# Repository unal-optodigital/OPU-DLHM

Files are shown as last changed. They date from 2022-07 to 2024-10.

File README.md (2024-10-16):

# Optical Pickup Units for DLHM: OPU-DLHM

This repo contains all the suplementary info and files related to the published paper "Adapting a Blu-ray Optical Pickup Unit as a Digital Lensless Holographic Microscopy Point Source". The circuit schematics and boards and the bill of materials will be found on this repo. As well as the most of our developements the info contained in this repo can be used for teaching and research purposes.

## Folders descriptions: 

- The circuit info folder contains the schematic and board design used to electronic-control of the OPU PHR-803T, the designs where adapted and modified from the schematics [presented by the team of Prof. Hwu](https://doi.org/10.1021/acssensors.8b00340).
- The bill of materials folder contains all the needed materials and some usefull .step CAD designs to incorporate the OPU in an standard 30 mm cage system. 

## Reference
Further information about this work can be found in the following publications. These are also the preferred way of citing this tool if you are implementing it in your own works.

- Heberley Tobón-Maya, Alejandra Gómez-Ramírez, Carlos Buitrago-Duque, and Jorge Garcia-Sucerquia, "Adapting a Blu-ray optical pickup unit as a point source for digital lensless holographic microscopy," Appl. Opt. 62, D39-D47 (2023).  
DOI: [10.1364/AO.474916](https://doi.org/10.1364/AO.474916).
- J. García-Sucerquia, C. Trujillo and J. F. Restrepo, "MICROSCOPIO, HOLOGRÁFICO SIN LENTES (MHDSL) Y MÉTODO PARA VISUALIZAR MUESTRAS," U.S. patent 7620179 (2018).

## Contact
- Jorge Garcia-Sucerquia ([jigarcia@unal.edu.co](mailto:jigarcia@unal.edu.co))
- Heberley Tobon-Maya (htobonm@unal.edu.co)
- Alejandra Gomez-Ramirez (alegomezram@unal.edu.co)
- Carlos A. Buitrago-Duque ([cabuitragod@unal.edu.co](mailto:cabuitragod@unal.edu.co))

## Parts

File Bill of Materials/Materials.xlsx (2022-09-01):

Bill of Materials
Designator | Item | Number | Cost Per Unit - USD | Total Cost - USD | Source of Materials | Material Type
Resistor | 2.2K resistor | 5 | 0.05 | 0.25 | Amazon or Aliexpress | Non-specific
Resistor | 18K resistor | 4 | 0.05 | 0.2 | Amazon or Aliexpress | Non-specific
Interface Cable | FFC to DIP 45 Pins | 1 | 1 | 1 | Amazon or Aliexpress | Non-specific
DIP SWITCH | DIP Switch 2 Pins | 1 | 0.25 | 0.25 | Amazon or Aliexpress | Non-specific
Condensers | 1800pF Condenser | 6 | 0.05 | 0.3 | Amazon or Aliexpress | Ceramic
Condensers | 33nF Condenser | 1 | 0.05 | 0.05 | Amazon or Aliexpress | Ceramic
Condensers | 22uF Condenser | 1 | 0.05 | 0.05 | Amazon or Aliexpress | Ceramic
Condensers | 100 uF Condenser | 1 | 0.05 | 0.05 | Amazon or Aliexpress | Ceramic
Condensers | 0.1 uF Condenser | 1 | 0.05 | 0.05 | Amazon or Aliexpress | Ceramic
OPAM | MCP6002(DIP) | 1 | 2 | 2 | Microchip | SemiConductor
Power driver | TC4425(DIP) | 3 | 1.45 | 4.35 | Microchip | SemiConductor

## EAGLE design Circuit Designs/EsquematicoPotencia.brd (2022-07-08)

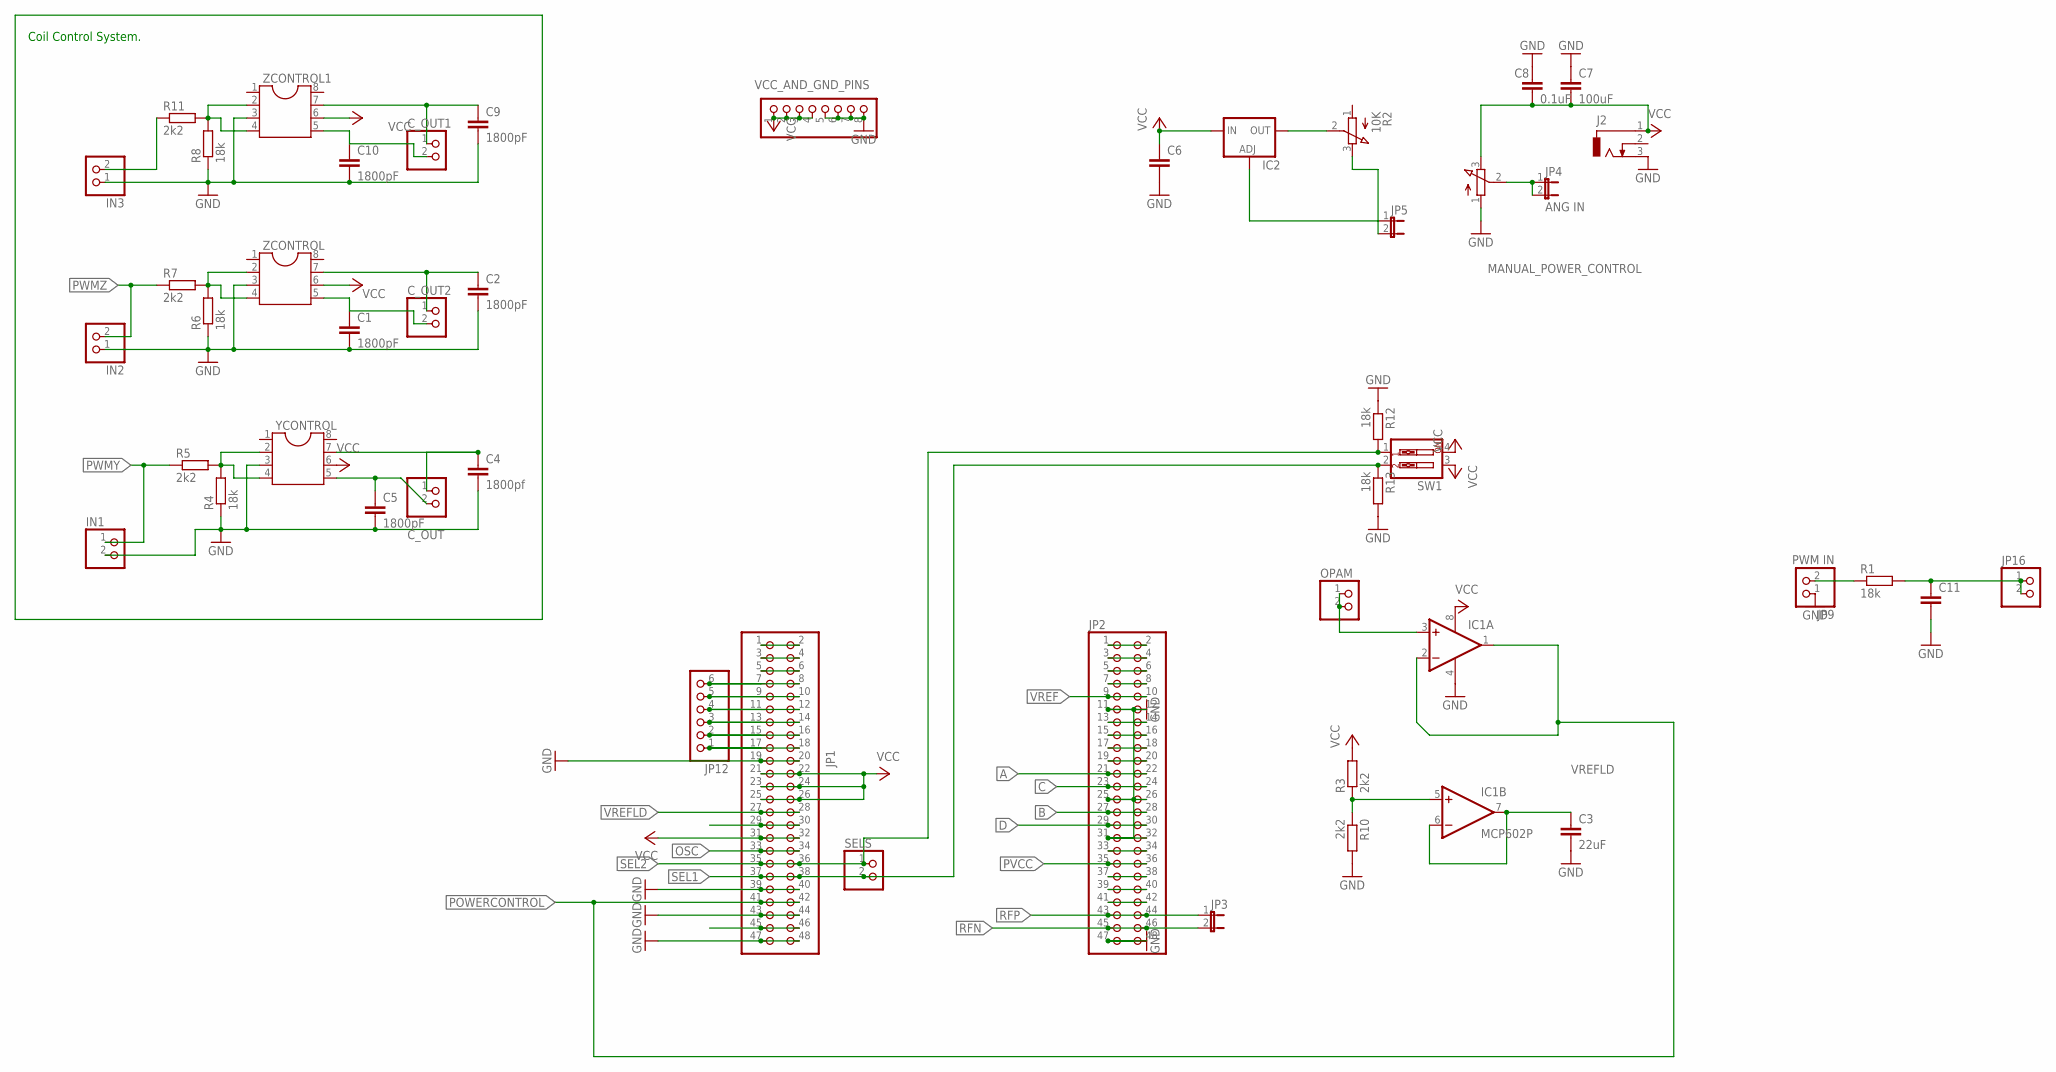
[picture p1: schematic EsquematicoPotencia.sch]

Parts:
C1, C2, C5, C9, C10: 1800pF; C025-024X044
C3: 22uF; C025-024X044
C4: 1800pf; C025-024X044
C6, C11: C-EU025-024X044; C025-024X044
C7: 100uF; C025-024X044
C8: 0.1uF; C025-024X044
C_OUT, C_OUT1, C_OUT2: PINHD-1X2; 1X02
IC1: MCP602P; DIL08
IC2: LM317TS; 317TS
IN1, IN2, IN3: PINHD-1X2; 1X02
J2: DCJ0303
JP1, JP2: PINHD-2X24; 2X24
JP3, JP5: JP1E; JP1
JP4: ANG IN; JP1
JP9: PWM IN; 1X02
JP12: PINHD-1X6; 1X06
JP16: PINHD-1X2; 1X02
MANUAL_POWER_CONTROL: 3RP/1610N
OPAM: PINHD-1X2; 1X02
R1, R4, R6, R8, R12, R13: 18k; 0204/7
R2: 10K; 3RP/1610N
R3, R5, R7, R10, R11: 2k2; 0204/7
SELS: PINHD-1X2; 1X02
SW1: SW_DIP-2; EDG-02
VCC_AND_GND_PINS: PINHD-1X8; 1X08
YCONTROL: DIL8; DIL08
ZCONTROL, ZCONTROL1: DIL8; DIL08

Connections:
A: JP2.21, JP2.22
B: JP2.27, JP2.28
C: JP2.23, JP2.24
D: JP2.29, JP2.30
GND: C1.2, C2.2, C3.2, C4.2, C5.2, C6.2, C7.1, C8.1, C9.2, C10.2, C11.2, IC1.4 (V-), IN1.2, IN2.1, IN3.1, J2.3, JP1.19, JP1.20, JP1.39, JP1.40, JP1.43, JP1.44, JP1.47, JP1.48, JP2.11, JP2.12, JP2.25, JP2.26, JP2.31, JP2.32, JP2.47, JP2.48, JP9.1, MANUAL_POWER_CONTROL.1 (A), R4.1, R6.1, R8.1, R10.2, R12.1, R13.2, VCC_AND_GND_PINS.5, VCC_AND_GND_PINS.6, VCC_AND_GND_PINS.7, VCC_AND_GND_PINS.8, YCONTROL.3, ZCONTROL.3, ZCONTROL1.3
unnamed: R8.2, R11.2, ZCONTROL1.2, ZCONTROL1.4
unnamed: JP1.1, JP1.2
unnamed: C11.1, JP16.1, JP16.2, R1.2
unnamed: R4.2, R5.2, YCONTROL.2, YCONTROL.4
unnamed: R6.2, R7.2, ZCONTROL.2, ZCONTROL.4
unnamed: JP1.29, JP1.30
unnamed: JP1.3, JP1.4
unnamed: IC1.5 (+IN), R3.1, R10.1
unnamed: JP4.1, JP4.2, MANUAL_POWER_CONTROL.2 (S)
unnamed: JP1.5, JP1.6
unnamed: JP2.1, JP2.2
unnamed: JP2.3, JP2.4
unnamed: JP1.45, JP1.46
unnamed: JP2.5, JP2.6
unnamed: JP2.7, JP2.8
unnamed: JP2.13, JP2.14
unnamed: JP2.15, JP2.16
unnamed: JP2.17, JP2.18
unnamed: JP2.19, JP2.20
unnamed: JP2.33, JP2.34
unnamed: JP2.37, JP2.38
unnamed: JP2.39, JP2.40
unnamed: JP2.41, JP2.42
unnamed: C2.1, C_OUT2.1, ZCONTROL.7
unnamed: C4.1, C_OUT.1, YCONTROL.7
unnamed: JP1.7, JP1.8, JP12.6
unnamed: C5.1, C_OUT.2, YCONTROL.5
unnamed: C1.1, C_OUT2.2, ZCONTROL.5
unnamed: JP9.2, R1.1
unnamed: IC1.3 (+IN), OPAM.1, OPAM.2
unnamed: IC2.1 (ADJ), JP5.1, JP5.2, R2.3 (E)
unnamed: IC2.2 (OUT), R2.2 (S)
unnamed: C9.1, C_OUT1.1, ZCONTROL1.7
unnamed: C10.1, C_OUT1.2, ZCONTROL1.5
unnamed: IN3.2, R11.1
OSC: JP1.33, JP1.34
POWERCONTROL: IC1.1 (OUT), IC1.2 (-IN), JP1.41, JP1.42
PVCC: JP2.35, JP2.36
PWMY: IN1.1, R5.1
PWMZ: IN2.2, R7.1
RFN: JP2.45, JP2.46, JP3.2
RFP: JP2.43, JP2.44, JP3.1
SEL1: JP1.37, JP1.38, R13.1, SELS.2, SW1.2
SEL2: JP1.35, JP1.36, R12.2, SELS.1, SW1.1
TILT2: JP1.17, JP1.18, JP12.1
VCC: C6.1, C7.2, C8.2, IC1.8 (V+), IC2.3 (IN), J2.1, JP1.21, JP1.22, JP1.23, JP1.24, JP1.25, JP1.26, JP1.31, JP1.32, MANUAL_POWER_CONTROL.3 (E), R3.2, SW1.3, SW1.4, VCC_AND_GND_PINS.1, VCC_AND_GND_PINS.2, VCC_AND_GND_PINS.3, VCC_AND_GND_PINS.4, YCONTROL.6, ZCONTROL.6, ZCONTROL1.6
VREF: JP2.9, JP2.10
VREFLD: C3.1, IC1.6 (-IN), IC1.7 (OUT), JP1.27, JP1.28
Y1: JP1.9, JP1.10, JP12.5
Y2: JP1.15, JP1.16, JP12.2
Z1: JP1.11, JP1.12, JP12.4
Z2: JP1.13, JP1.14, JP12.3

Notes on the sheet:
Coil Control System.

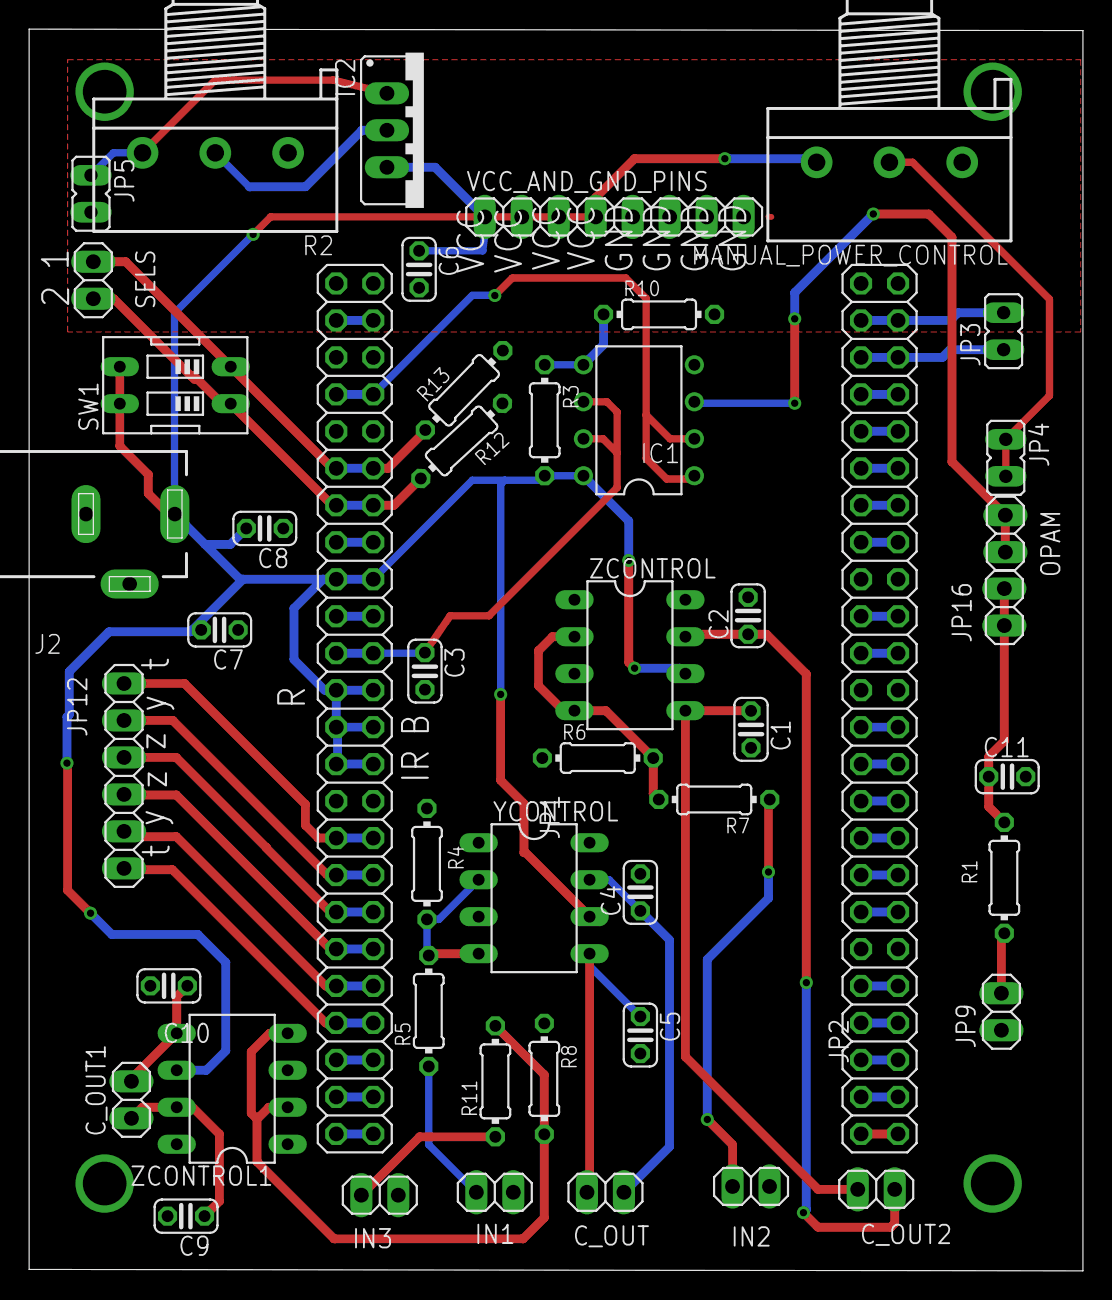
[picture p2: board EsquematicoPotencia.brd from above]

Board: 2 copper layers, 72.4 x 85.3 mm, 48 parts (0 on the bottom side), 57 nets.

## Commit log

2022-07-08 Initial commit
    Initial commit with folders structure
    [EsquematicoPotencia.brd, EsquematicoPotencia.sch, Materials.xlsx]
2022-09-01 Update Materials.xlsx
    The BoM file has been updated
    [Materials.xlsx]
